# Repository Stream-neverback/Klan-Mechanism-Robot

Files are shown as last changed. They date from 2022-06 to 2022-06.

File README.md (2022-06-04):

# Klan-Mechanism-Robot
视频链接：
https://www.bilibili.com/video/BV1mr4y1x7gJ/







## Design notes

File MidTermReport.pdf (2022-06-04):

Fundamental of Machine Design | Group Project Report

1 / 19

## Fundamental of Machine Design

## Mid-Term Report

## Thorough Design, Manufacture & Analysis

Group Member: 王思尧 11810210, 江轶豪 11912404, 张亭亭 11910335,

孟子竣 11810810, 张宇阳 11810123, 王澍原 11810314

### 1 Overall Layout & Information of The Crab Robot Based on Klann

Mechanism

### 1.1 Number of Legs

Foot robot generally has two, four, six and eight legs. Differences among types of robots in motion form and function is analyzed.

Biped walking robot is suitable for walking on uneven or obstructed ground. It has stronger flexibility and better mobility than other ordinary mobile robots. However, the biped walking model is a variable structure mechanism, with the single foot support an open chain, and the double foot support a closed chain. The fixation of the support points depends on the friction force to ensure that the mass distribution and weight have a direct impact on the static and dynamic stability. In order to ensure the stability of posture during walking, the gait of walking needs very strict constraints, which is not particularly easy to achieve.

Hexapod robot is also called mimic-spider robot. Hexapod robot is a robot that mainly imitates the limb structure and movement control strategy of insects and other arthropods. Compared with the quadruped robot, the hexapod robot has better stability, because it is easier to meet the spatial stability condition of β≥ 3/2n, which is very suitable to complete the unstructured and uncertain environment operation. Nevertheless, its limbs have redundancy.

Octa-legged robots are usually designed for specific research purposes on the basis of hexapod robots. They do not have the redundancy characteristics of hexapod robots, while keeping the characteristics of specific bionic creatures. In this experiment, our team selected a crab-like eight-legged robot, consisting of three parts, the foot movement body, the connection structure and the control system. The principal body of the foot movement is the carrier platform of the bionic crab robot, which is mainly composed of two sets of quadruped movement mechanism of gear crank connecting rod and support plate mounted symmetrically. It is driven by the walking stepping motor to realize the basic movements such as transverse walking and steering. The control system is mounted on the principal

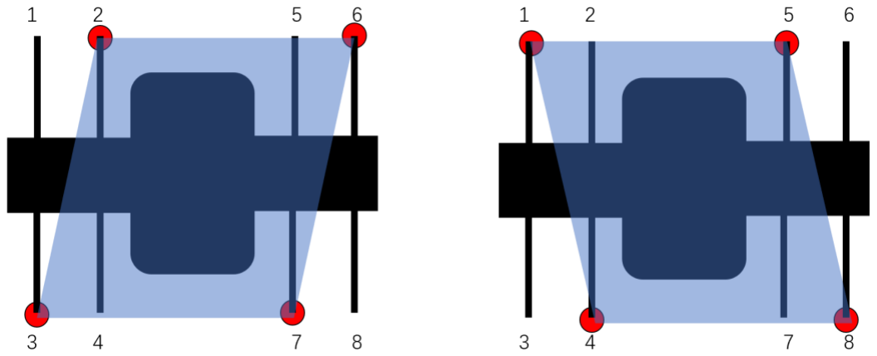
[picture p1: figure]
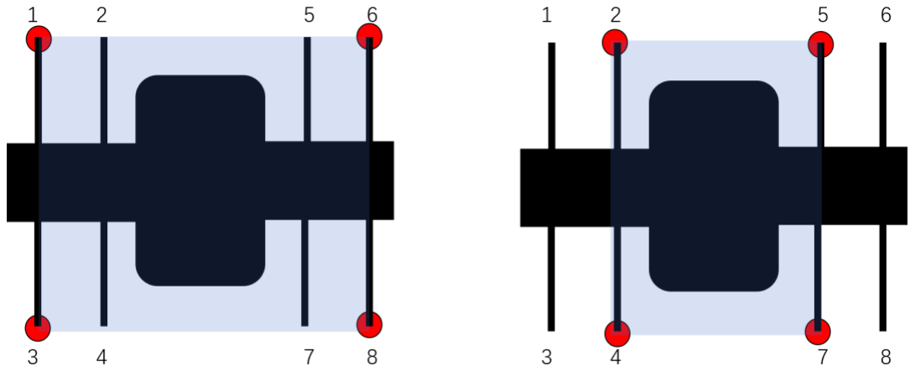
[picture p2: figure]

2 / 19

body of the foot movement. The stepper motor drive module and the steering gear drive module control the rotation Angle and speed of the stepper motor and steering gear by receiving infrared control signals, so as to realize the drive of the corresponding structure.

### 1.2 The Gait of the Robot

The gait optimization is to stabilize the robot posture and fully deliver the power from the motor. The gait of the robot should allow the robot to maintain standing in every phase of the motion. In this case, we need 4 points to contact the ground at any time. We can divide 8 legs into 2 groups, each group of 4 points contact the ground at the same time in a particular phase of motion. And to maintain the support surface area in two phases to be the same. We design the robot gait as shown below. We call it (2,3,6,7), (1,4,5,8).

(2,3,6,7), (1,4,5,8) gait & its support polygon There are other gaits of 8-leg robot as well, including (2,4,5,7), (1,3,6,8). However, the varying area of support polygon of this gait may affect the stability of the robot.

(2,4,5,7), (1,3,6,8) gait& its support polygon Eventually, we decided to choose the (2,3,6,7), (1,4,5,8) gait to maintain maximum stability of the robot.

### 1.3 Distribution of Robot Components

3 / 19

To balance the whole body, it is necessary to make the mass distribute uniformly. Basically, the robot is designed as a carb-like structure. The motor is placed in the middle with 8 legs assembled on each side. Battery pack is next to the motor. Both of them are attached to the main body. By this way, mass distribution will be balanced well and the overall structure will be fairly stable. The motor transmits moment of force as source power to rotate the main shaft. The main shaft drives eight legs consequently. Legs are installed to the main body by rotatable linkages. Meanwhile they are linked to the main shaft by gears. On each side, there are four legs moving in the same mode but out of phase.

### 1.4 Dimensions of Robot & Speed Expectation

The robot size is preliminary decides about 300mm*300mm*200mm. We design the size with reference to the motor. Similarly, depends on the performance of the motor, the speed is expected to be around 0.5~1m/s.

### 2 Mathematical Analysis of Klann linkage mechanism

### 2.1 Formulations of the equations of motion for legged robots with closed-

loop mechanism
To describe the behavior of a multibody system (MBS) by using the equation of motion, the vector of generalized coordinates for the system can be written as

q = [q1

T q2 ⋯

T qn
T
]

T
(1)

where qi = [xi yi θi

]i

T
is the vector of planar Cartesian generalise coordinate for an MBS. And for an arbitrary joint k between body i and body j, relative conditions are posed by a kinematic constraint

Фk

K(i,j) = (ri + Ai si
′k
) − (rj + Aj sj

′k
)

= (

xi + xi

′k
cosθi − yi

′k
sinθi − xj − xj

′k
cosθj + yj

′k
sinθj
yi + xi

′k
sinθi + yi

′k
cosθi − yj − xj

′k
sinθj − yj

′k

cosθ) = 0, | (2)

where ri

is the vector to the centroid of the body, Ai is the rotation transformation matrix, and si

′k
is the local representation of the body fixed vector to point k.
According to the configuration of the MBS defined by n vectors of generalized coordinates of q where t is the time, a set of kinematic constraint equations Ф is obtained as

Ф(q,t) = [

ФK(q)
ФD(q,t)
] = 0, | (3)

where ФK(q) is the kinematic constrain equation and ФD(q,t) denotes the driving

constraints of the MBS.
The first derivative of Eq. (3) with respect to time is used to obtain the velocity constraint equation while the second derivative of Eq. (3) with respect to time yields the acceleration

4 / 19

constraint equation as:
Фqq̇ = v, | (4)
Фqq̈= γ, | (5)

Where Фq is the Jacobian matrix of the kinematic constraint equations, υ is the velocity equation, and γ is the acceleration equation.
Through the virtual power principle, they are shown as:

Mq̈+ Фq

Tλ = g, (6)

### 2.2 The constraints and mathematical model of Klann mechanism

For original Klann mechanism, it is known as the system with 12 links, and an attachment with the ground. The generalized coordinates are defined as follows:

q = [q1

T q2

T q3

T q4

T q5

T q6
T q7

T q8

T q9

T q10

T q11

T q12

T q13

T
]

T
(7)

Therefore, 39 ( = 13 × 3 ) elements are obtained in the generalised coordinates in our present analysis. As the equation shown below, the first 38 elements derive from ФK(q) in Eq. (3), and the last element derive from ФD(q,t) which is the driving constraint.

5 / 19

Ф(q,t) =

[

x1 − l1 cos θ1
y1 − l1 sin θ1
x2 + l2 cos θ2 − x1 − l1 cos θ1 y2 + l2 sin θ2 − y1 − l1 sin θ1 x3 − l3 cos θ3 − x2 + l2 cos θ2 y3 − l3 sin θ3 − y2 + l2 sin θ2 x4 − l4 cos θ4 − x3 − l3 cos θ3 y4 − l4 sin θ4 − y3 − l3 sin θ3 x7 + l7 cos θ7 − x6 − l6 cos θ6 y7 + l7 sin θ7 − y6 − l6 sin θ6 x9 − l9 cos θ9 − x8 + l8 cos θ8 y9 − l9 sin θ9 − y8 + l8 sin θ8 x11 − l11 cos θ11 − x10 + l10 cos θ10 y11 − l11 sin θ11 − y10 + l10 sin θ10 x12 + l12 cos θ12 − x11 − l11 cos θ11 y12 + l12 sin θ12 − y11 − l11 sin θ11 x4 + l4 cos θ4 − x2 − l2 cos θ2 y4 + l4 sin θ4 − y2 − l2 sin θ2 x5 + l5 cos θ5 − x2 + l2 cos θ2 y5 + l5 sin θ5 − y2 + l2 sin θ2 x7 − l7cos θ7 − x4 + l4cos θ4 y7 − l7sin θ7 − y4 + l4sin θ4 x8 + l8cos θ8 − x3 − l3cos θ3 y8 + l8sin θ8 − y3 − l3sin θ3 x9 + l9cos θ9 − x7 − l7cos θ7 y9 + l9sin θ9 − y7 − l7sin θ7 x10 + l10cos θ10
y10 + l10sin θ10
x12 + l12cos θ12
y12 + l12sin θ12
x5 − l5cos θ5 − x10 + l10cos θ10 y5 − l5sin θ5 − y10 + l10sin θ10 x6 − l6cos θ6 − x12 − l12cos θ12 y6 − l6sin θ6 − y12 − l12sin θ12 θ11 −

π
2
x13 − l13cos θ13 − x9 + l9cos θ9 y13 − l13sin θ13 − y9 + l9sin θ9 θ13 − θ9
θ1 + ωt | ]

= 0 , (8)

And the figure below shows the generalized Klann mechanism, whose linkages have their own x and y coordinate axis for the rotational angle of each joint, and the length of links and other parameters are known, where l1 to l13 are link lengths. However, in our actual project, we will eliminate link BC, link BA, link CD and link CE, replaced by the links, every one of which will have an extra joint, and the shapes can be designed like a triangular. (Both transformations are equivalent and cannot modify the degree of freedom).

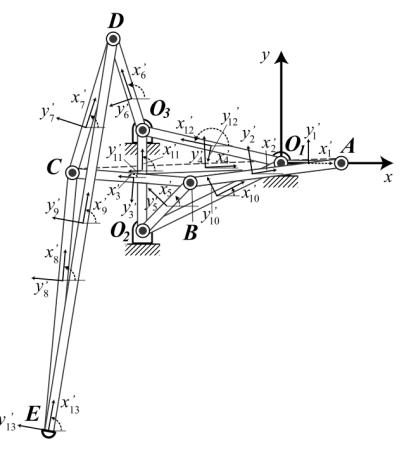
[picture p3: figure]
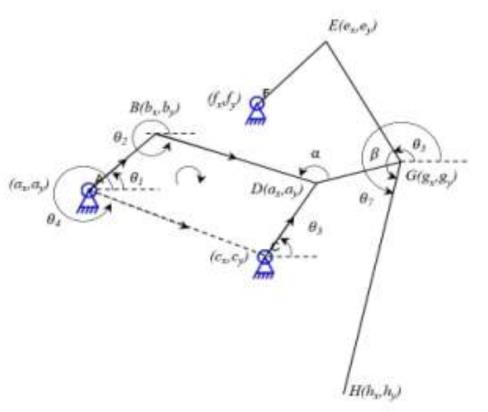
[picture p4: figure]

6 / 19

Fig. 1: Generalized coordinates on the Klann mechanism

### 2.3 Optimization Technique

Step height and stride length are the two most important parameters of the foot locus, which are the consideration and targets of the optimization. Higher the step height, better will

be the all-terrain capability to overcome obstacles, also, longer the stride length is, faster the

robot finishes the same displacement. Therefore, the objective of the optimization is to maximizing the coordinates of step height (xsh, ysh) and stride length (xsl, ysl).

### Max(xsℎ, ysℎ, xsl, ysl) = f(θin, l1, l2, l3 … ln) , (9)

Now we use this figure as a sample of modelling, considering a close-loop equation for loop ABDC.

Fig. 2: Kinematic representation of Klann’s linkage

r⃗1 + r⃗2 − r⃗3 − r⃗4 = 0 , (10) r1e

iθ1 + r2e

iθ2 − r3e

iθ3 − r4e

iθ4 = 0 , (11)
r1(cosθ1 + isinθ1) + r2(cosθ2 + isinθ2) − r3(cosθ3 + isinθ3) − r4(cosθ4 + isinθ4) =
0 , (12)

7 / 19

Then locating the coordinates of Point D

dx = r1cosθ1 + r2cosθ2 = acosθ1 + bcosθ2 , (13) dy = r1sinθ1 + r2sinθ2 = asinθ1 + bsinθ2, (14)

Then there is the position analysis of output link GH

ℎx = gx + gcosθ7, (15)
ℎy = gy + gsinθ7, (16)

### 2.4 Simulation results and analysis

Table.1 Link Length & Foot Locus Parameters of Klann Mechanism.
Link | Iteration Result
| 1(mm)

### Iteration Result

2(mm)

### Iteration Result 3(mm)

1

137.1 | 84.9 | 110.2

2

64.2 | 39.5 | 77.4

3

88.6 | 63.2 | 68.4

4

226.8 | 150.3 | 150.3

5

122.7 | 99.5 | 99.5

6

347.9 | 241.0 | 240.9

7

84.3 | 55.3 | 55.3

8

102.8 | 56.4 | 56.4

9

133.3 | 96.9 | 102.9

10

234.8 | 151.4 | 159.4

11

60.2 | 49.2 | 49.2

12

50.9 | 36.0 | 26.0
Result | Stride Length: 276.12mm
Step Height: 242.8mm | Stride Length: 218.2mm
| Step Height: 56.74mm | Stride Length: 74.18mm
| | Step Height: 73.41mm

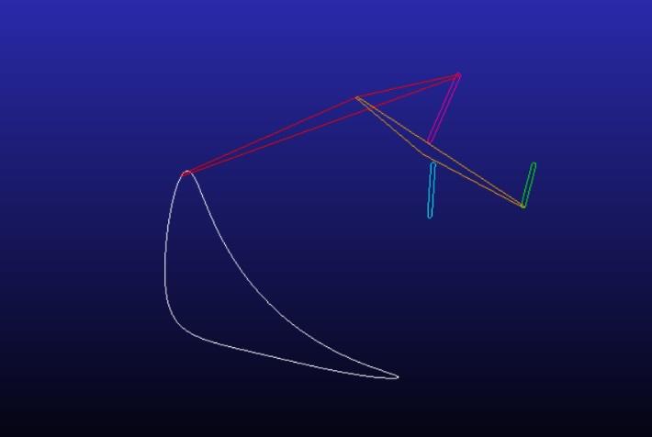
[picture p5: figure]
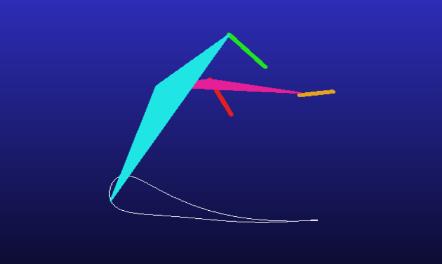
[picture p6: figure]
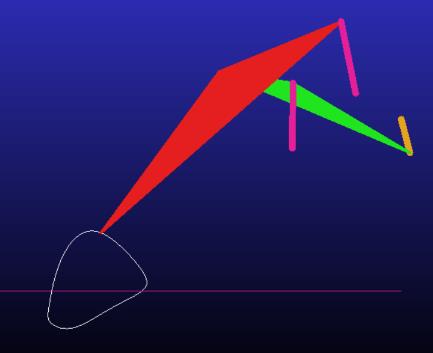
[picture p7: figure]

8 / 19

Stride Length: Model 1 > Model 2 > Model 3 Step Height: Model1 > Model 3 > Model 2

(a)

(b)

(c)
Figure.3 (a) (b) (c) Foot trajectories obtained using ADAMS for results 1, 2 & 3 respectively

In order to determine which iteration result is the most suitable one, step height and stride length should be concerned. For the comparison, step height will weigh less, because the target of the competition is to reach the destination in a faster speed and stability is more important, which pose a challenge to us to reduce the displacement change of gravity center during the

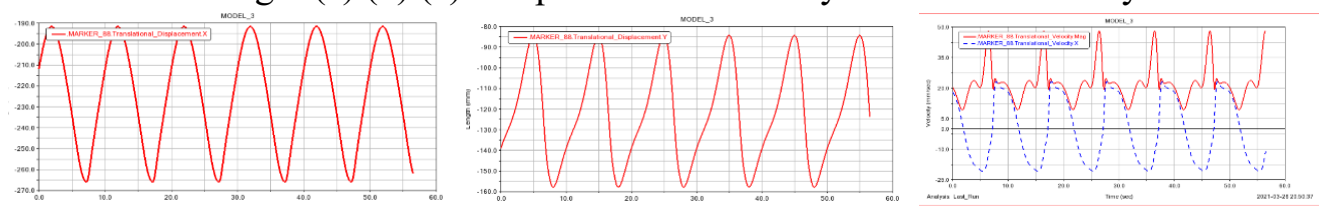
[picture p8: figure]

9 / 19

march in one period. Also, the optimization of the magnitude velocity, is to be more stable to have a better command of phase control.

(a) | (b) | (c)
Fig.4 (a) (b) (c): Displacement on x & y axis & the velocity of model 1

Fig.5 (a) (b) (c): Displacement on x & y axis & the velocity of model 2

Fig.6 (a) (b) (c): Displacement on x & y axis & the velocity of model 3

Table.2 The magnitude of velocity change of different models
Model # | Speed Change (mm/s)
Model 1 | 132.0
Model 2 | 72.1
Model 3 | 42.3

Velocity Change: Model 1 > Model 2 > Model3

### 2.5 Conclusion on Motion Analysis

Stride Length: Model 1 > Model 2 > Model 3
Step Height: Model 1 > Model 3 > Model 2
Speed Change: Model 1 > Model 2 > Model3
Through estimating the overall performance of each link parameter, The link model 2 became our option of the solution.

### 3 Simulation & Calculation

### 3.1 Torque Analysis

We conducted an analysis of the relation between the foot end force and the torque of the transmission shaft. The robot’s eventual weight is about 1kg. There are 4 legs contact with the ground at a time. Therefore, approximately divided by 4, we applied a 3 newtons force on one of the foot end vertically to simulate the gravity force. Another force of friction of 0.15N is also applied to the foot end.
The torque curve of the shaft is shown below.

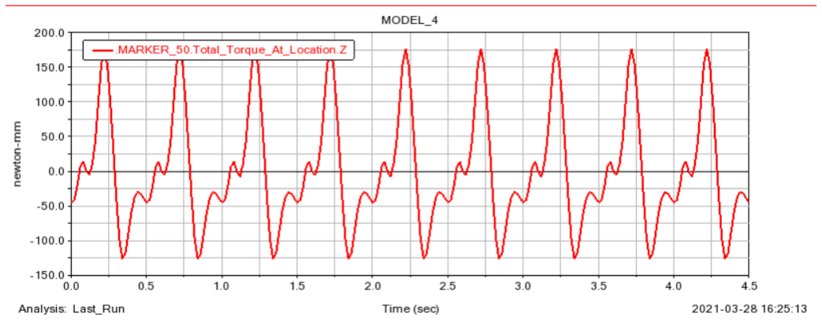
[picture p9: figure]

10 / 19

Through this curve, the maximum torque is about 0.176N·m, which determines the

torque that one leg delivers to the shaft. There are 4 legs making contact with the

ground at any time. The summed torque is 0.704N·m, which is below the output

Torque of the motor. By applying a safety factor of 2, the output shaft should sustain

a torque of 1.4N·m. Therefore, the transmission rate is determined no more than

1:0.7.

### 3.2 Power & Motor

The battery pack has a male input charging wire and a female output wire. Both of them are 5.5*2.1mm connector. Use a couple of adapters with wires to connect the output connector of the battery to the motor pins. The wires are welded to the pins of the motor.
The properties of motor and battery are listed as followed:
Motor properties
Mass | 192.5g
Input voltage | 24V
Scale | See sketch below
Revolution speed (empty load) | 300r/s
Current (empty load) | 0.13A
Revolution speed (full load) | 245r/s
Current (full load) | 0.62A
Rated moment | 2Nm
Stall moment | 20Nm
Stall current | 2.19A
power | 10W
Reduction ratio | 16.6

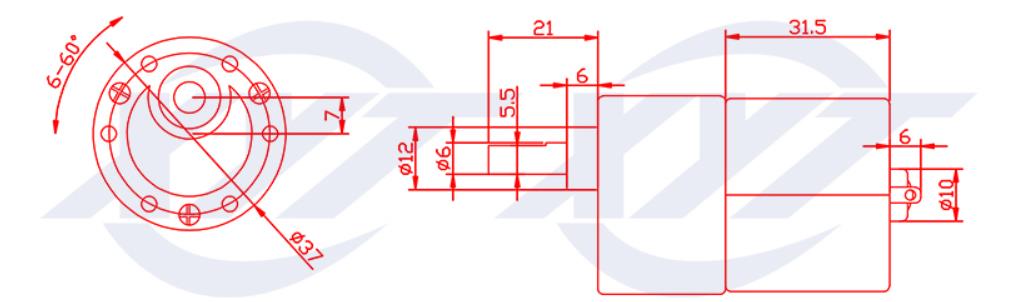
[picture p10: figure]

11 / 19

Battery pack properties
Mass | 389.5g
Voltage (output) | 24V
Current | 4A (stable) 10A (maximum)
Capacity | 300mAh
Scale | 132*68*49mm
Charging voltage and current | 25.2V 1A

### 3.3 Transmission Ratio

As for transmission device, we chose a simple scheme, the motor will drive Gear1, which connected with Gear2 and drive the Main drive shaft, then the drive shaft can drive the robot. Gear1 is spur gear with keyways and screw holes to connect with motors, and Gear2 is spur gear with hexagonal hole connects with the shaft. Gears is made of stainless steel. And the shaft is hexagonal, two ends of the shaft connect with gears that can drive the robot. The shaft is still made of stainless steel. The motor will be arranged horizontally. The advantages of this transmission mode are simple structure, easy to dismantle and inspect, small transmission loss and low cost of course. Since the robot will be made of aviation laminated plate, it will be light, so the stainless-steel shaft is basically not bearing payload force.

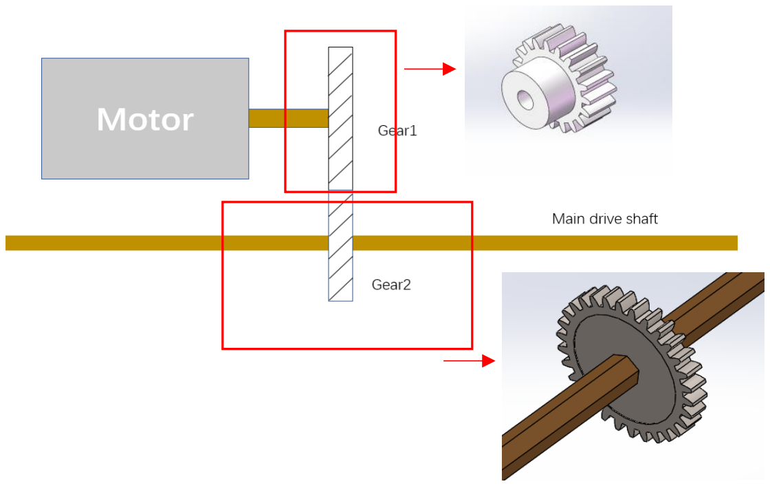
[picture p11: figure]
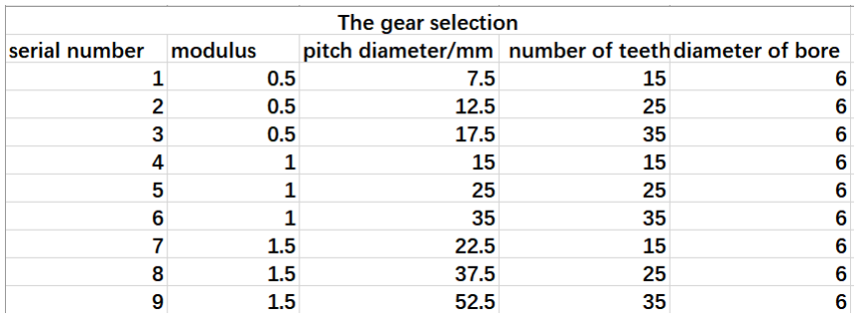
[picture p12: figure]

12 / 19

### 3.4 Gear selection

Through searching on the Internet, we found several suitable motor boss gears, whose parameters are shown in the table below:

Our design is to try through gears of different sizes but with the same diameter sum of the reference circle, and finally get a gear combination with higher speed and stability.

### 4 CAD Design of The Crab Robot

It is essential to build a 3D CAD model in a virtual environment in advance to validate the idea and link with the manufacture process. In this project, SolidWorks is used as the 3D CAD tool to help with designing.
The Robot is mainly made of 3D printed material, PLA. Enabling the robot component to have a better degree of freedom in designing. The assembly graph and some of the engineering drawings are shown below.

### 4.1 Assembly Drawing

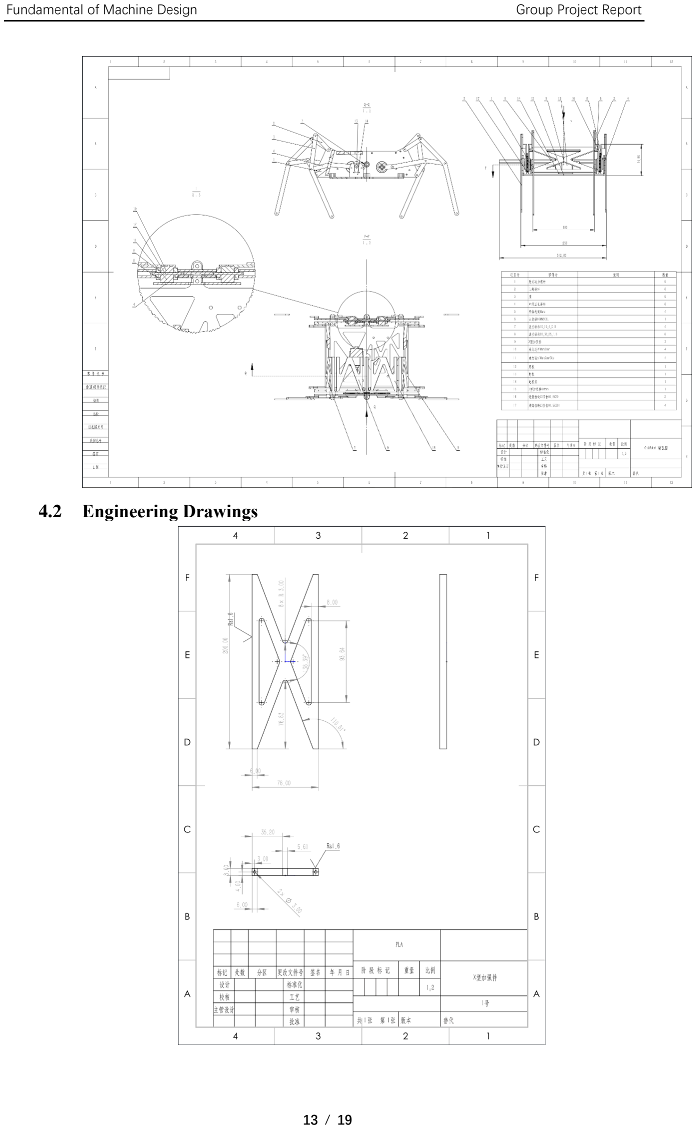
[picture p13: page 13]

13 / 19

### 4.2 Engineering Drawings

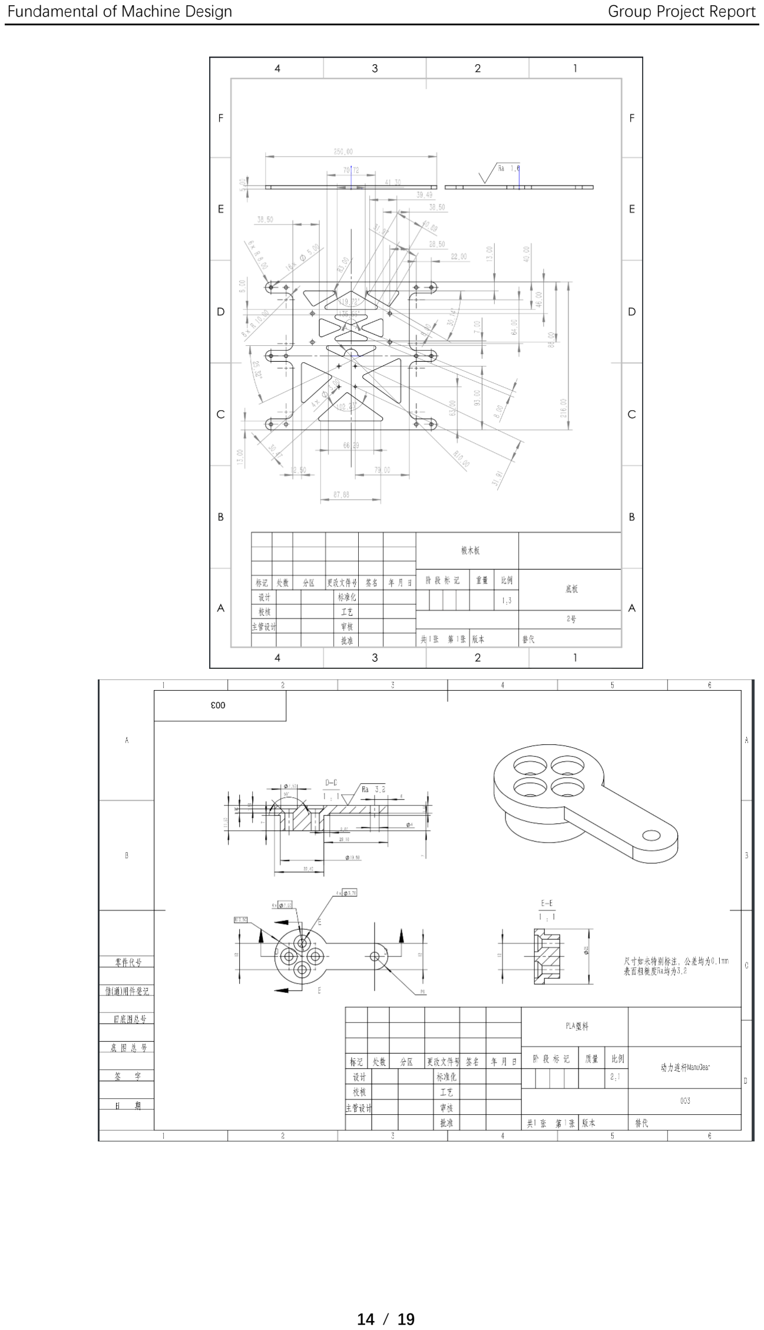
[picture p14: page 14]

14 / 19

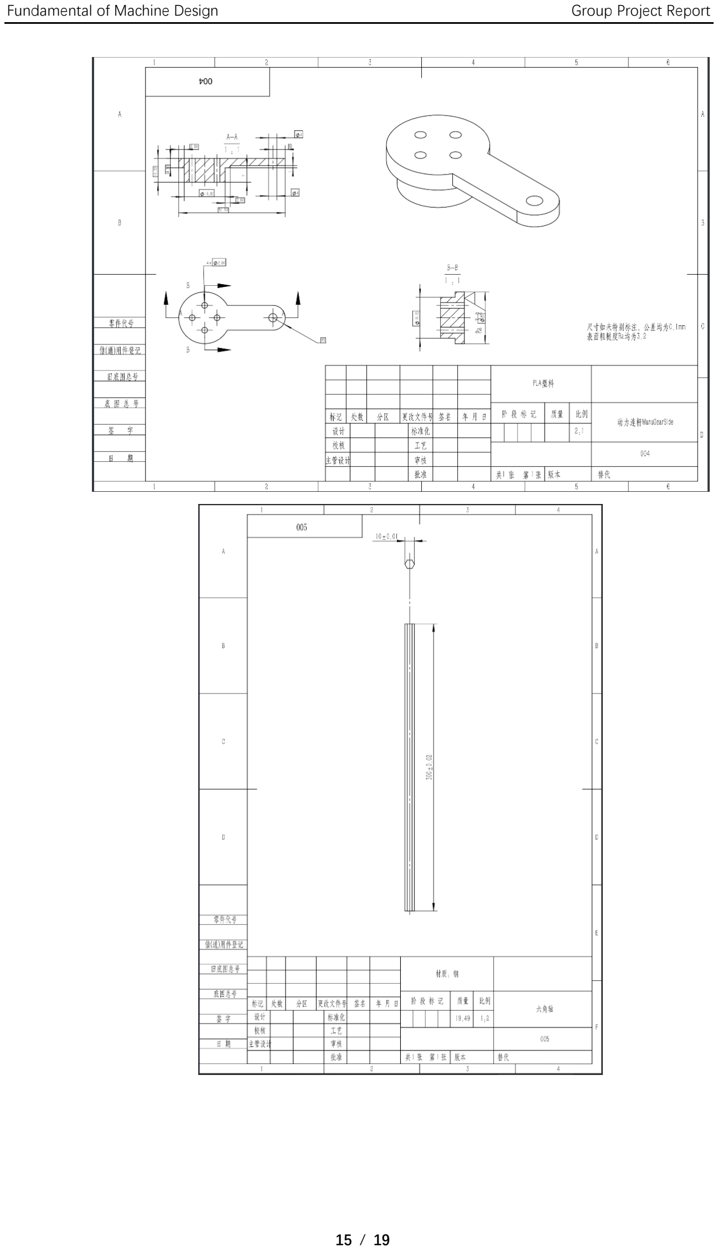
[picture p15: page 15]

15 / 19

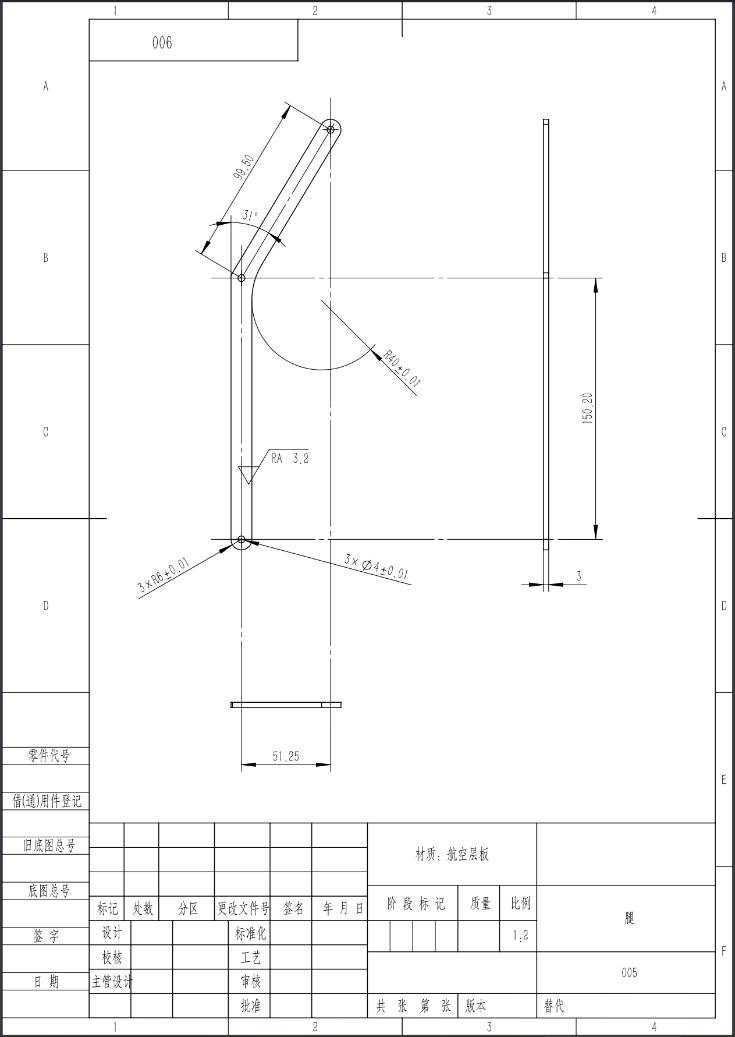
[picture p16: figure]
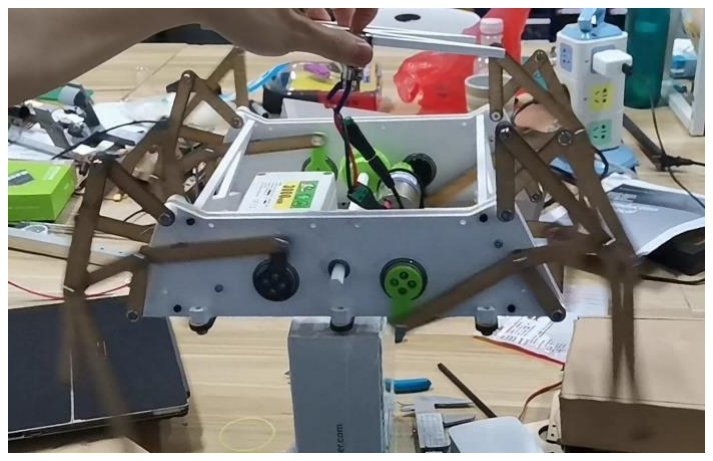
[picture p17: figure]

16 / 19

### 5 Manufacture of The Robot

Manufacture of the robot mainly used 3D printing and laser cutting, which combines the benefit of 3D printing and laser cutting.
The manufactured prototype is shown below.

Fig. Manufactured Prototype

### 6 Current Problems & Desirable Adjustment

### 6.1 Stiffness Problem of the 3D Printed Shaft

When applied force or torque on the gear on the shaft, the shaft will move

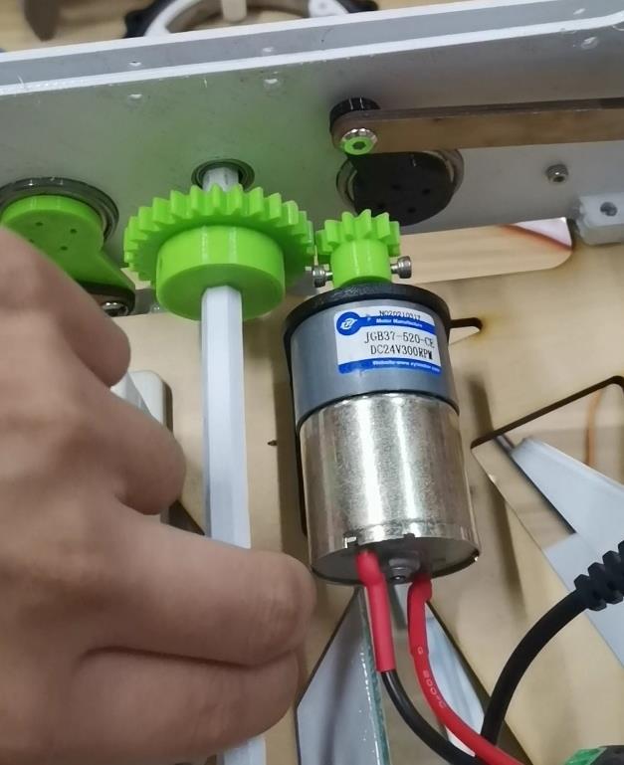
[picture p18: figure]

17 / 19

fromits original position due to poor stiffness of the shaft. Causing the increase of distance between gears. Eventually causing the slipping of gears.

Fig. Radial Deviation Caused by Insufficient Stiffness of Shaft

### 6.2 Friction Between Links Using Bolt & Nut Connection

Using the bolt nut connection between the links is easy to assemble and light weight. But the friction is increased when tightening the bolts, causing the robot to lose power.

### 6.3 Axial Spacing of the Center Shaft

In the first-generation design, the shaft is not entirely fixed axially but free to move. The only force holding the shaft in its position is friction force. The shaft will gradually deviate from the center position and causing the gear to be disengaged.

### 7 Further Iterations & Upgrades

7.1 Material Upgrades In original edition, we use aeronautical laminate, made of birch and basswood, as major material throughout the whole design. Compared with normal materials, specifically, metal and acrylic, its relatively light weight and high stiffness is of our interest. Taking advantages of aeronautical laminate into consideration, we find carbon fiber, a widely used aeronautical material, seem to be an alternation. In domains of weight and stiffness, carbon fiber has a much better performance than aeronautical laminate. Meanwhile, other advantages including high tensile strength, high chemical resistance, high temperature tolerance and low thermal expansion expand working limitation in extreme and unexpecting environments.

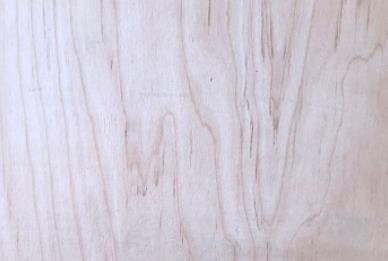
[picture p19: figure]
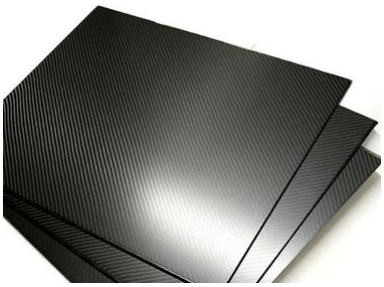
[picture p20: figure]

18 / 19

Fig. Aeronautical Laminate

Fig. Carbon Fiber Plate

7.2 Linkage Upgrades We develop two ways to optimize the linkage of our robot. During our further experiment, we can observe and simulate proper ration between gaits and gears, through which our robot can maintain high velocity while outputting applicable torque to overcome rough walking condition. In other aspect, we first use normal joint design, which is composed of bolts and nuts. However, such combination could provide quite high frictional considering large quantities of joints. Hence, we can use flange bearings and thrust bearings to form joints in order to eliminate vast friction. However, the high weight of such bearings, especially multiplying large number of joints, is another problem we need to face.

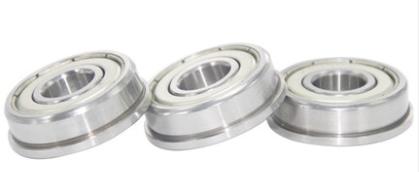
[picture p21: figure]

19 / 19

Fig. Flange Bearings
7.3 Control System Our robot is only capable of one-dimension motion. Therefore, it is of great importance to develop control system to achieve higher dimension missions. First and foremost, we can design H-bridge circuit to achieve forward and backward motion. On the other hand, we can develop swarm robot system to control a group of walking robots, which implies a promising application potential.

### 8 References:

[1]. 基于齿轮传动的结构仿生螃蟹机器人设计 秦慧斌，郑智贞；

[2].仿螃蟹机器人步行运动平稳控制及仿真分析 王珏

[3].仿蟹机器人步态规划及复杂地貌行走方法研究 王刚

[4]. Pratik Walimbe. (2018). EFFECT OF VARIATION OF ANGLES OF TERNARY LINKS ON THE GAIT PATTERN OF KLANN’S MECHANISM. International Journal of Research in Engineering and Technology, 7(8), 126-131. [5]. Komoda, Kazuma, & Wagatsuma, Hiroaki. (2017). Energy-efficacy comparisons and multibody dynamics analyses of legged robots with different closed-loop mechanisms. Multibody System Dynamics, 40(2), 123-153.
[6]. Sheba, Jaichandar Kulandaidaasan, Elara, Mohan Rajesh, Martínez-García, Edgar, & Tan-Phuc, Le. (2017). Synthesizing reconfigurable foot traces using a Klann mechanism. Robotica, 35(1), 189-205.

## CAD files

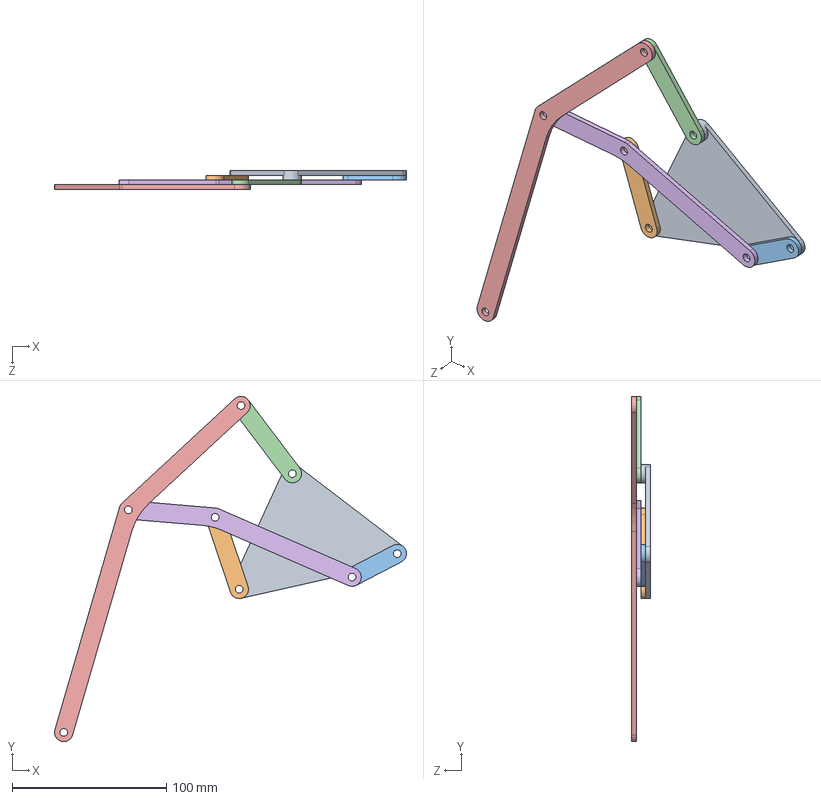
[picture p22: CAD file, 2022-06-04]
仿真构件.SLDASM
228.2 x 223.8 x 12.0 mm
整体构架
底无动力连杆
动力连杆
上部连杆
腿
中间三孔连杆

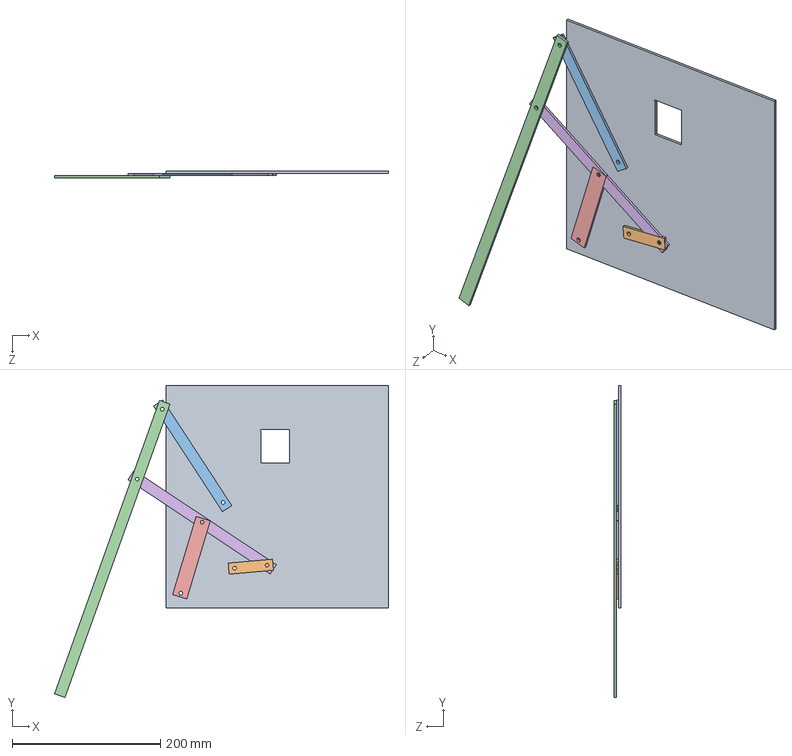
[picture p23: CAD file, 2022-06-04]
装配体1.SLDASM
450.2 x 420.6 x 9.00 mm
BottomPlate
2H05LEVER
2H15LLEVER
2H1L3LLEVER
2H1LLEVER
3H2LLEVER

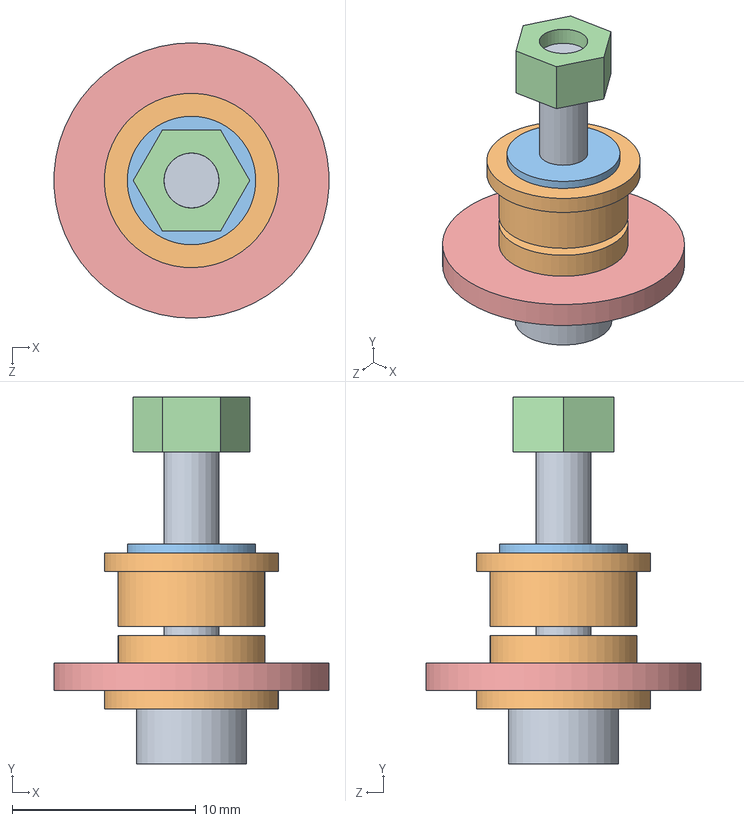
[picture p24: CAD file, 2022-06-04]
连杆Sol.SLDASM
15.0 x 20.0 x 15.0 mm
ThroughAxialBolt
法兰轴承3_8_9.5_H4_F1 x 2
垫片3_7_0.5
M3螺母
垫片8_15_1.5

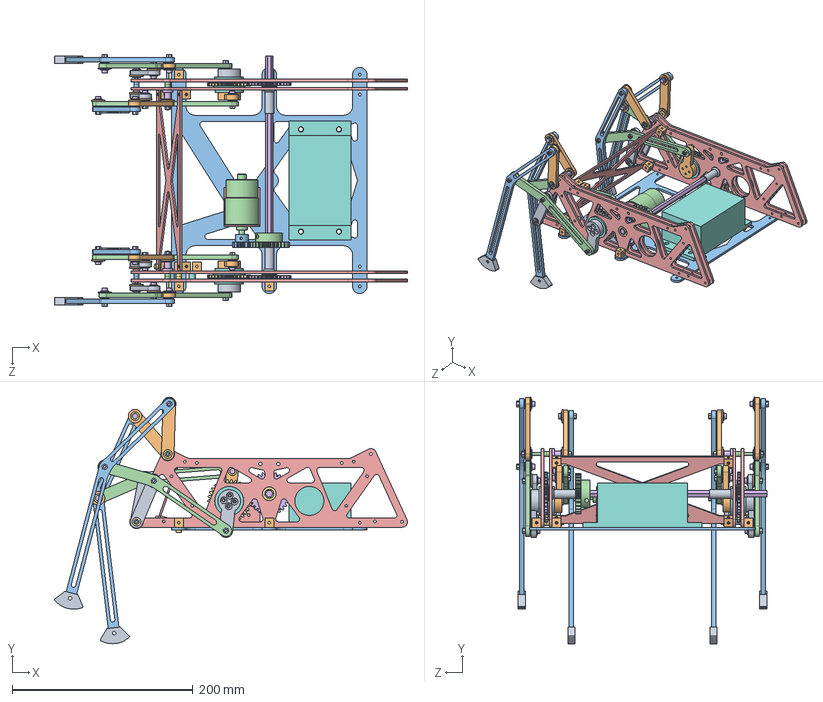
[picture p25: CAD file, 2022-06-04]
01SpiderManuGen2.SLDASM
390.1 x 272.4 x 278.0 mm
底无动力连杆 x 4
上部连杆 x 4
腿 x 4
中间三孔连杆 x 4
整体构架Manu x 4
六角轴10MM300L
法兰轴承10_15_4_0.8 x 4
法兰轴承20_32_25_1.5 x 4
动力连杆ManuGear x 2
动力连杆ManuGearSide x 2
底板
电机
电机架
边侧齿轮L2直齿M1.5X30 x 2
腿部齿轮L3直齿M1.5X301 x 2
battery
六角轴套 x 2
六面螺母M3_10 x 10
Motore直齿M1.5X12
Shaft直齿M1.5X28
X型加强件
ThroughAxialBolt x 16
法兰轴承3_8_9.5_H4_F1 x 48
垫片3_7_0.5 x 16
M3螺母 x 24
垫片8_15_1.5 x 20
螺丝M3_35 x 4
螺丝M3_25 x 4
轴套3_d7_H2 x 2
轴套3_d7_H10 x 2
螺丝M3_6 x 4
边缘垫套筒 x 2
足端 x 4

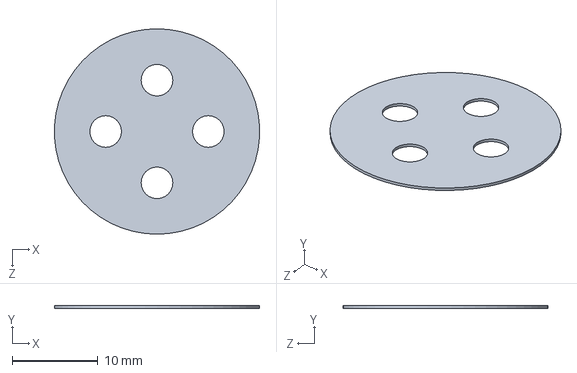
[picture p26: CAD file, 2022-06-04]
轴承垫片.SLDPRT
24.0 x 0.3 x 24.0 mm

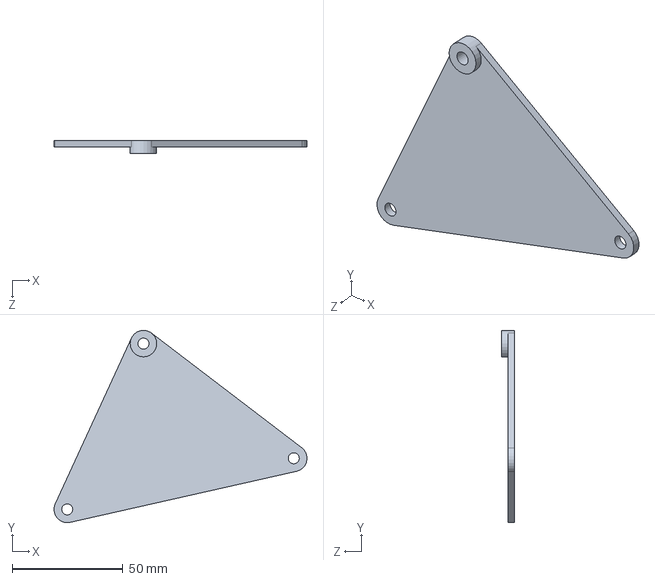
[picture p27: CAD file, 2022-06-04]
整体构架.SLDPRT
114.4 x 87.0 x 6.00 mm

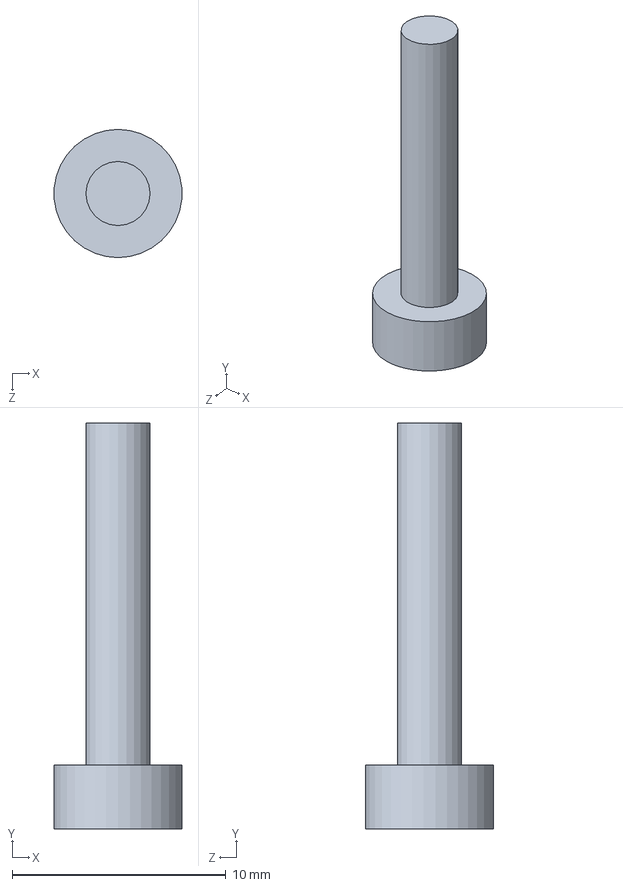
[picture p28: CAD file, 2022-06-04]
螺丝M3_35.SLDPRT
5.97 x 19.0 x 6.00 mm

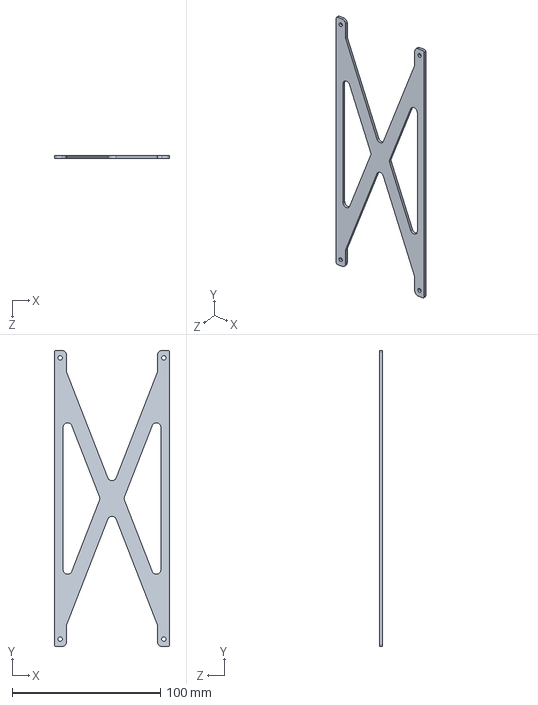
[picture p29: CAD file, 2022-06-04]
X型加强件.SLDPRT
78.0 x 200.0 x 2.00 mm

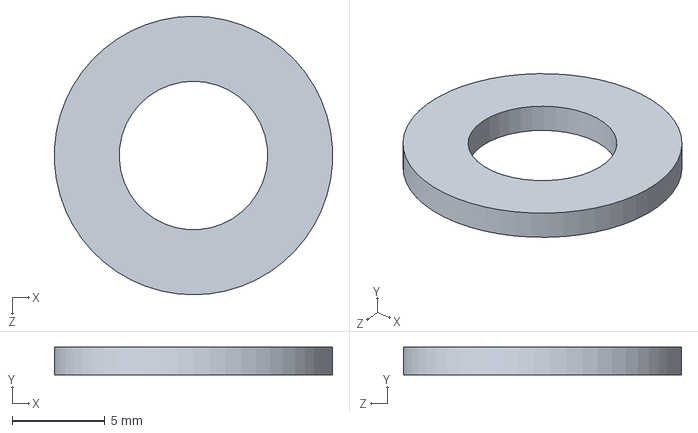
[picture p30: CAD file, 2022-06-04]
垫片8_15_1.5.SLDPRT
15.0 x 1.50 x 15.0 mm

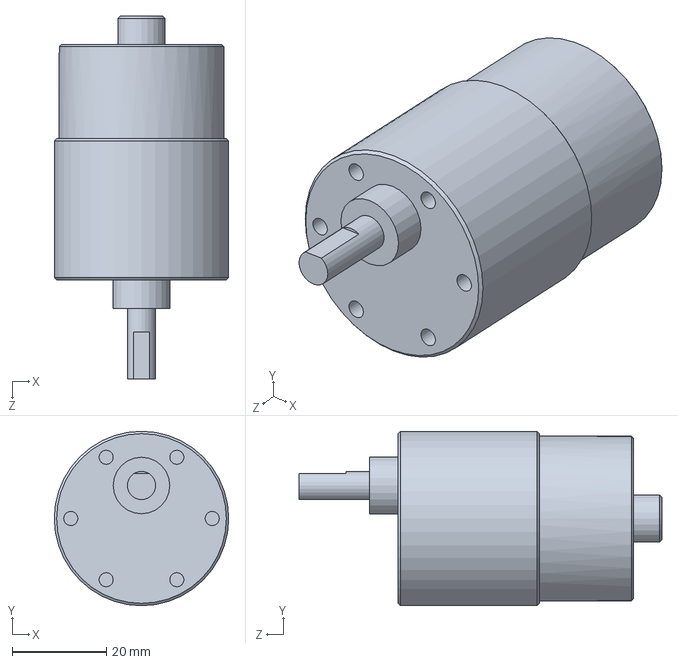
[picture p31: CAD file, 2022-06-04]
电机.SLDPRT
37.0 x 37.0 x 77.0 mm

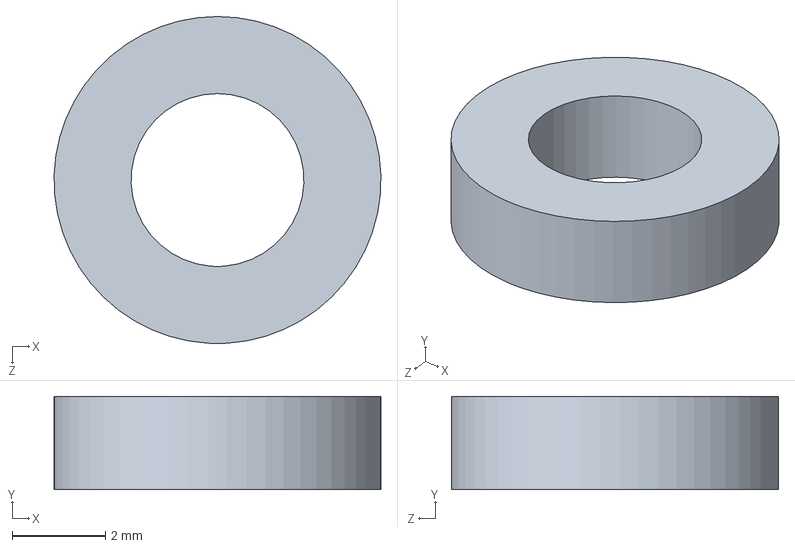
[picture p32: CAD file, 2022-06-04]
轴套3_d7_H2.SLDPRT
7.00 x 2.00 x 7.00 mm

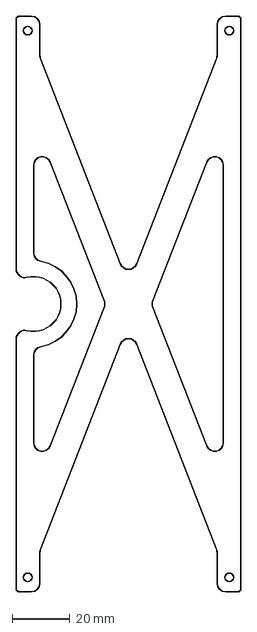
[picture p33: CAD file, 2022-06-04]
1x2mmX型加强件Botton.DXF
78.0 x 200.0 mm

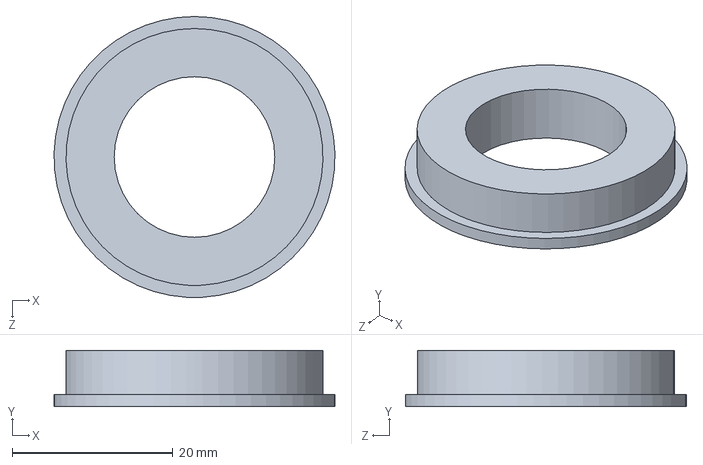
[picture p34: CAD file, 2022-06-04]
法兰轴承20_32_25_1.5.SLDPRT
35.0 x 7.00 x 35.0 mm

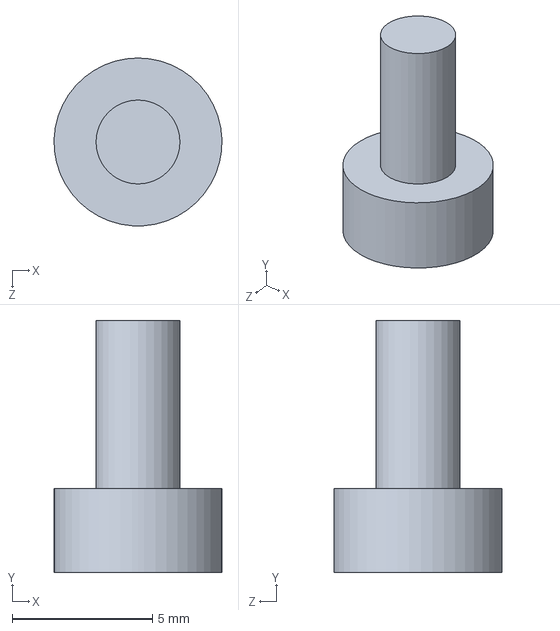
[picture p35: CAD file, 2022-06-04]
螺丝M3_6.SLDPRT
6.00 x 9.00 x 6.00 mm

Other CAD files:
battery.SLDPRT
4x3mm整体构架板.DXF
动力连杆ManuGearSide.SLDPRT
8x5mm腿.DXF
1x2mmX型加强件.DXF
1x3mm底板.DXF
2x4mm边侧齿轮L2直齿M1.5X30.DXF
4x3mm腿部齿轮L3直齿M1.5X30.DXF
8x5mm上部连杆.DXF
8x5mm中间三孔连杆.DXF
8x5mm底无动力连杆.DXF
AM六角轴10MM300L.SLDPRT
M3螺母.SLDPRT
Motore直齿M1.5X12.SLDPRT
Shaft直齿M1.5X28.SLDPRT
ThroughAxialBolt.SLDPRT
X型加强件Botton.SLDPRT
上部连杆.SLDPRT
中间三孔连杆.SLDPRT
六角轴10MM300L.SLDPRT
六角轴套.SLDPRT
六面螺母M3_10.SLDPRT
动力连杆.SLDPRT
动力连杆Manu.SLDPRT
动力连杆ManuGear.3MF
动力连杆ManuGear.SLDPRT
动力连杆ManuGearSide.3MF
垫片3_7_0.5.SLDPRT
底无动力连杆.SLDPRT
底板.SLDPRT
整体构架Manu.SLDPRT
法兰轴承10_15_4_0.8.SLDPRT
法兰轴承3_8_9.5_H4_F1.SLDPRT
电机架.SLDPRT
腿.SLDPRT
腿部齿轮L3直齿M1.5X301.SLDPRT
螺丝M3_25.SLDPRT
足端.sldprt
轴套3_d7_H10.3MF
轴套3_d7_H10.SLDPRT
轴承垫片.3MF
边侧齿轮L2直齿M1.5X30.SLDPRT
边缘垫套筒.3MF
边缘垫套筒.SLDPRT
